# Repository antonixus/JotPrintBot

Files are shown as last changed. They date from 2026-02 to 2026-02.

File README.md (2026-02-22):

# JotPrintBot




<p align="center">
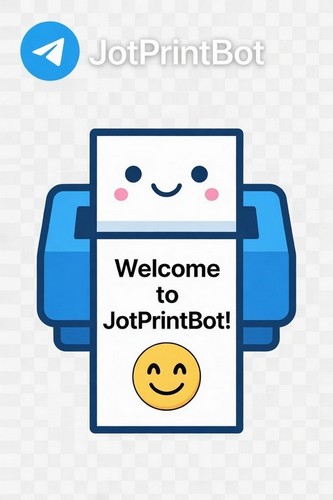
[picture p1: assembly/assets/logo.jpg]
JotPrintBot Logo
  
</p>

## Introduction

**JotPrintBot** is an asynchronous Python application that allows you to print text from Telegram messages to a thermal receipt printer. Send a message to the bot, and it will be printed on paper via a connected ESC/POS thermal printer.

**Supported hardware:**

- **CSN-A2 TTL** thermal printer (and other ESC/POS compatible models)
- **Raspberry Pi** / **DietPi** (serial connection via `/dev/serial0` or similar)
- Any Linux system with a serial or USB-Serial thermal printer

The bot uses [aiogram](https://docs.aiogram.dev/) for Telegram integration and [python-escpos](https://python-escpos.readthedocs.io/) for printer control.

---

## Functionality

- **Print text** — Send any text message (up to 1000 characters); it will be wrapped to the printer’s font width and queued for printing:
  - `FONT=a` (Font A): 32 characters per line
  - `FONT=b` (Font B): 42 characters per line
- **Print images** — Send a photo; it is resized to printer width (384 pixels), optionally rotated if landscape, and queued for printing. **Image enhancement** (contrast, sharpness, brightness, grayscale, dithering) improves thermal printer output quality
- **Whitelist access** — Only users in the whitelist can use the bot; others receive "Access denied"
- **Rate limiting** — 1 print per 10 seconds per user by default (configurable via `PRINT_RATE_LIMIT_SECONDS`)
- **Telegram formatting → printer styles** (when `PRINT_TELEGRAM_FORMATTING=true`):
  - `*bold*` → bold / emphasized text
  - `__underline__` → underlined text
  - `~strikethrough~` → inverted text (white‑on‑black style via `invert=True`)
  - `` `code` `` / triple‑backtick blocks → printed with Font **B** (`font='b'`, more compact/monospaced)
  - `> blockquote` → double‑size text (`double_height=True`, `double_width=True`)
  - `_italic_` entities are currently **ignored**
- **Commands:**
  - `/start` — Welcome message and usage instructions
  - `/status` — Check if the printer is online and paper status (adequate / near-end / no paper)
  - `/help` — List commands and limits
  - `/qr <text>` — Print the given text as a QR code (UTF-8 safe, supports Cyrillic)
- **Mock mode** — Run without a physical printer for development (`MOCK_PRINTER=true`)
- **Error handling** — Exceptions are logged and the admin is notified via Telegram

---

## Installation and Configuration

### Requirements

- Python 3.8+ (3.12 recommended)
- Serial thermal printer (or mock mode for testing)

On Raspberry Pi / Debian you also need some system libraries for Pillow and Tk:

```bash
sudo apt update
sudo apt install -y \
  libtiff6 libjpeg-dev zlib1g-dev libfreetype6-dev \
  liblcms2-dev libwebp-dev tcl8.6-dev tk8.6-dev python3-tk
```

### 1. Clone the repository

```bash
git clone https://github.com/antonixus/JotPrintBot.git
cd JotPrintBot
```

### 2. Create virtual environment and install dependencies

```bash
python -m venv venv
# Linux/macOS:
source venv/bin/activate
# Windows:
venv\Scripts\activate

pip install -r requirements.txt
```

### 3. Run setup (creates config, folders, and systemd service)

```bash
python setup.py
```

Setup creates the `logs/` folder, `.env` (if missing), and generates `bot.service` for systemd. On Raspberry Pi, install the service with:

```bash
python setup.py --install-service
```

### 4. Configure `.env`

Edit `.env` in the project root:

| Variable | Required | Description |
| --- | --- | --- |
| `BOT_TOKEN` | Yes | Telegram bot token from[@BotFather](https://t.me/BotFather) |
| `ADMIN_ID` | Yes | Your Telegram user ID (for error notifications) |
| `WHITELIST` | Yes | Comma-separated Telegram user IDs allowed to use the bot |
| `SERIAL_PORT` | No | Serial device (default:`/dev/serial0`) |
| `BAUDRATE` | No | Baud rate (default:`9600`) |
| `MOCK_PRINTER` | No | `true` to run without hardware (default: `false`) |
| `FONT` | No | Printer font code for python-escpos (default:`a`) |
| `DENSITY_LEVEL` | No | Print density 0–8 (default:`4`) |
| `PRINT_RATE_LIMIT_SECONDS` | No | Seconds between prints per user (default:`10`) |
| `PRINT_HEADER_ENABLED` | No | Print a header before every print (default:`true`) |
| `HEADER_LINE_WIDTH` | No | Header rule width in characters (default:`42`) |
| `CODEPAGE` | No | Python codec name for text encoding before sending to printer (default:`cp1251`) |
| `CODEPAGE_ID` | No | ESC/POS code page ID used with`ESC t` (on many printers `6` is cp1251; default: `6`) |
| `PRINTER_PROFILE` | No | python-escpos printer profile name (default:`RP326`) |
| `MEDIA_WIDTH_PIXELS` | No | Printer media width in pixels |
| `MEDIA_WIDTH_MM` | No | Printer media width in mm |
| `TEXT_UNDERLINE` | No | Default underline mode (0/1) for printer text (default:`0`) |
| `TEXT_ALIGN` | No | Default alignment for printer text:`left`, `center`, or `right` (default: `left`) |
| `TEXT_WIDTH` | No | Default width multiplier for printer text (default:`1`) |
| `TEXT_HEIGHT` | No | Default height multiplier for printer text (default:`1`) |
| `TEXT_INVERT` | No | Default invert mode (0/1) for printer text (default:`0`) |
| `TEXT_SMOOTH` | No | Default smoothing for printer text (default:`false`) |
| `TEXT_FLIP` | No | Default flip mode for printer text (default:`false`) |
| `SERIAL_BYTESIZE` | No | Serial byte size (default:`8`) |
| `SERIAL_PARITY` | No | Serial parity (default:`N`) |
| `SERIAL_STOPBITS` | No | Serial stop bits (default:`1`) |
| `SERIAL_TIMEOUT` | No | Serial timeout in seconds (default:`1.0`) |
| `SERIAL_DSRDTR` | No | Enable DSR/DTR flow control (default:`true`) |
| `QR_SIZE` | No | Default QR code pixel size 1–16 (default:`3`) |
| `QR_ALIGN` | No | Base alignment before printing QR codes:`left`, `center`, or `right` (default: `center`) |
| `QR_DENSITY` | No | Print density used for QR codes (default:`3`) |
| `QR_CENTER` | No | Center QR image when using software-rendered QR (default:`false`, example: `true`) |
| `QR_IMG_IMPL` | No | Image implementation for QR rendering:`bitImageRaster`, `graphics`, or `bitImageColumn` (default: `bitImageRaster`, example: `bitImageColumn`) |
| `IMAGE_IMPL` | No | ESC/POS image command for image printing:`bitImageRaster`, `graphics`, or `bitImageColumn` (default: `bitImageRaster`) |
| `IMAGE_FRAGMENT_HEIGHT` | No | Max height per fragment for large images (default:`960`) |
| `IMAGE_CENTER` | No | Center image horizontally (requires`MEDIA_WIDTH_PIXELS` to be set; default: `false`) |
| `IMAGE_DENSITY` | No | Print density for images (0–8, default:`5`) |
| `IMAGE_PRINT_WIDTH` | No | Target width in pixels for image resizing (default:`384` for CSN-A2) |
| `IMAGE_ENHANCE_ENABLED` | No | Enable/disable image enhancement (default:`true`) |
| `IMAGE_CONTRAST` | No | Contrast enhancement factor (default:`1.5`) |
| `IMAGE_SHARPNESS` | No | Sharpness enhancement factor (default:`2.0`) |
| `IMAGE_BRIGHTNESS` | No | Brightness adjustment factor (default:`1.0`) |
| `IMAGE_GRAYSCALE` | No | Convert to grayscale before printing (default:`true`) |
| `IMAGE_DITHERING` | No | Apply Floyd-Steinberg dithering for smooth gradients (default:`true`) |

**Raspberry Pi / DietPi:** Enable serial in `raspi-config` → Interface Options → Serial Port.

The printer connection uses UART serial. Many ESC/POS printers work with 9600 baud, 8N1, and (depending on model) may require DSR/DTR flow control. This project defaults to those values (see the “Printing Text” example in the CircuitDigest guide) and you can override them via `.env` if needed. See: [Thermal Printer Interfacing with Raspberry Pi](https://circuitdigest.com/microcontroller-projects/thermal-printer-interfacing-with-raspberry-pi-zero-to-print-text-images-and-bar-codes).

---

## Assembly

To build a portable JotPrintBot with a CSN-A2 printer and Raspberry Pi Zero W (including PD power and step-down to 5 V), follow the step-by-step guide:

**[Assembly instructions](assembly/ASSEMBLY_INSTRUCTIONS.md)** — BOM, wiring schematic, and wiring steps.

You can **3D print a printer case** to house the thermal printer, Raspberry Pi, and wiring. STEP and Bambu Lab Studio (3mf) model files are in [`assembly/3D_printing/`](assembly/3D_printing/); the same assembly instructions document includes recommended print settings (PLA, layer height, supports, etc.).
Or use prepared Bambulab printing profile: [Makerworld Bambulab Studio project](https://makerworld.com/ru/models/2431859-jotprintbot-portable-telegram-thermal-printer#profileId-2667653)

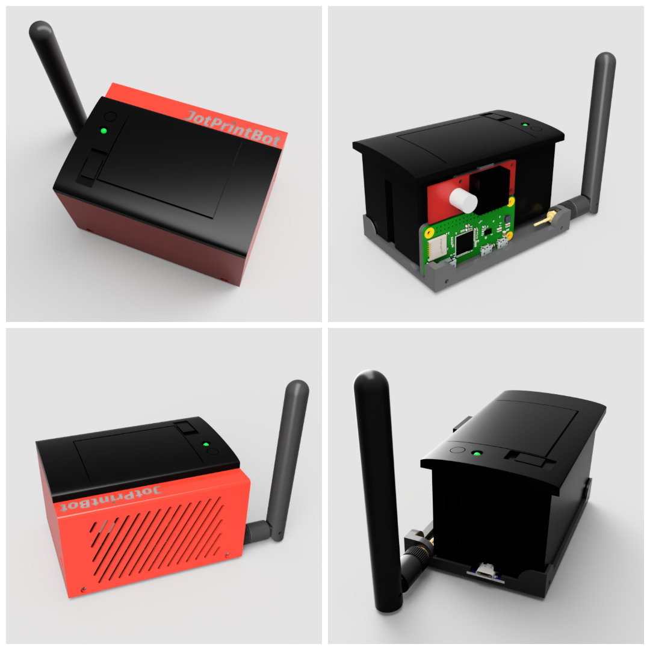
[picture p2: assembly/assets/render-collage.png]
JotPrintBot 3d model render


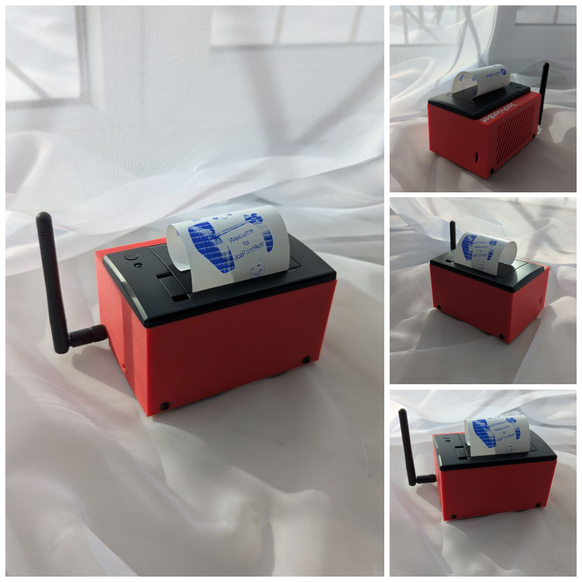
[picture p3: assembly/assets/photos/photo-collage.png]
JotPrintBot real device photo collage

---

## Usage

### Launch the application

```bash
python bot.py
```

The bot will start polling for updates. Send a message to your bot on Telegram to print it.

#### Run in background (screen)

```bash
screen -S bot python bot.py
```

Detach with `Ctrl+A`, then `D`. Reattach with `screen -r bot`.

#### Run as systemd service (Raspberry Pi)

Setup generates `bot.service` with the correct paths. Install for auto-start on boot:

```bash
python setup.py --install-service
sudo systemctl start bot
```

Or manually: copy `bot.service` to `/etc/systemd/system/`, edit paths if needed, then `sudo systemctl daemon-reload && sudo systemctl enable bot && sudo systemctl start bot`.

View status: `sudo systemctl status bot`. View logs: `journalctl -u bot -f`.

### Commands

| Command | Description |
| --- | --- |
| `/start`  | Welcome message and basic instructions |
| `/status` | Check if the printer is online and paper status |
| `/help` | List all commands and limits |
| `/qr` | Print a QR code with the given text |

### Limits

- **Rate:** 1 print per 10 seconds per user (default, configurable via `PRINT_RATE_LIMIT_SECONDS`)
- **Text length:** Maximum 1000 characters per message

### Image Printing

Send a photo to the bot to print it. The image will be:

- **Automatically resized** to the printer width (384 pixels for CSN-A2, configurable via `IMAGE_PRINT_WIDTH`)
- **Orientation handling:** Landscape images are rotated 90° clockwise before printing
- **Aspect ratio preserved:** Images are scaled proportionally to fit the printer width
- **Fragmentation:** Large images are automatically split into fragments (configurable via `IMAGE_FRAGMENT_HEIGHT`)
- **Image enhancement:** Improves print quality with contrast, sharpness, brightness, grayscale conversion, and dithering (configurable via `IMAGE_ENHANCE_ENABLED`, `IMAGE_CONTRAST`, `IMAGE_SHARPNESS`, `IMAGE_BRIGHTNESS`, `IMAGE_GRAYSCALE`, `IMAGE_DITHERING`)

**Supported formats:** JPEG, PNG (as sent by Telegram)

**Configuration options** (in `.env`):

- `IMAGE_IMPL`: Image printing command (`bitImageRaster`, `graphics`, or `bitImageColumn`)
- `IMAGE_FRAGMENT_HEIGHT`: Maximum height per fragment (default: `960`)
- `IMAGE_CENTER`: Center image horizontally (requires `MEDIA_WIDTH_PIXELS`; default: `false`)
- `IMAGE_DENSITY`: Print density 0–8 (default: `5`)
- `IMAGE_PRINT_WIDTH`: Target width in pixels (default: `384` for CSN-A2)
- `IMAGE_ENHANCE_ENABLED`: Enable/disable image enhancement (default: `true`)
- `IMAGE_CONTRAST`: Contrast enhancement factor (default: `1.5`)
- `IMAGE_SHARPNESS`: Sharpness enhancement factor (default: `2.0`)
- `IMAGE_BRIGHTNESS`: Brightness adjustment factor (default: `1.0`)
- `IMAGE_GRAYSCALE`: Convert to grayscale before printing (default: `true`)
- `IMAGE_DITHERING`: Apply Floyd-Steinberg dithering for smooth gradients (default: `true`)

**Note:** Pillow is required for image processing and is listed in `requirements.txt`. On Raspberry Pi, ensure system libraries for Pillow are installed (see Installation section).

### Image Enhancement

The bot applies image preprocessing techniques to improve thermal printer output quality:

- **Grayscale conversion** — Thermal printers work best with B&W images
- **Contrast enhancement** — Improves black/white distinction
- **Sharpness enhancement** — Makes edges more defined
- **Brightness adjustment** — Optimizes for thermal paper
- **Floyd-Steinberg dithering** — Smooth gradients for thermal printing

**Configuration** (in `.env`):

```bash
IMAGE_ENHANCE_ENABLED=true
IMAGE_CONTRAST=1.5
IMAGE_SHARPNESS=2.0
IMAGE_BRIGHTNESS=1.0
IMAGE_GRAYSCALE=true
IMAGE_DITHERING=true
```

For fine-tuning parameters for your specific printer, see [`DEPLOYMENT_GUIDE.md`](DEPLOYMENT_GUIDE.md:1).

---

## Tests

The project uses [pytest](https://docs.pytest.org/) with [pytest-asyncio](https://pytest-asyncio.readthedocs.io/) for async tests.

### Run all tests

```bash
pytest test/ -v
```

### Image enhancement tests

```bash
pytest test/image_enhancement.py -v   # Unit tests for image enhancement
pytest test/test_printer.py -v        # Integration tests for image printing
```

### Run specific test files

```bash
pytest test/test_printer.py -v   # Printer module with mock (text & QR)
pytest test/test_wrapping.py -v  # Font-based wrapping expectations
pytest test/test_encoding.py -v  # Cyrillic encoding on real printer (requires hardware)
```

### Test coverage

Tests cover:

- **Printer (mock):** Initialization, `print_text`, `print_qr`, `print_task`, `status`, and image printing (`_do_print_image`) in mock mode
- **Image enhancement:** Unit tests in `test/image_enhancement.py` for `_enhance_image()` (contrast, sharpness, brightness, grayscale, dithering, and disabled path)
- **Wrapping helper scripts:** How many characters fit per line for different fonts
- **Encoding helper script:** Cyrillic output validation using the configured printer profile and code page

For QR-specific manual testing, you can also use:

```bash
python -m test.qr_print_test "Hello" --impl bitImageColumn --center
```

---

## Logging

Logging is configured with a **rotating file handler**:

- **File:** `logs/app.log`
- **Max size:** 10 MB per file
- **Backup count:** 5 (keeps up to 5 rotated files)
- **Level:** INFO

**Logged events include:**

- `Message received` — When text is queued for printing
- `Printed` / `Printed (mock)` — When a print job completes
- Errors with full tracebacks (print failures, handler exceptions, status check failures)

Logs are written to `logs/` (created automatically on startup). Ensure the application has write permissions to the project directory.

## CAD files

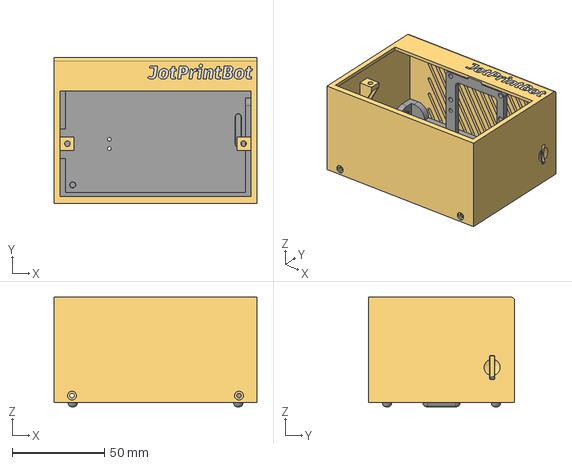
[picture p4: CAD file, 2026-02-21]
assembly/3D_printing/Printer Case.step
110.0 x 79.3 x 59.5 mm
Case bottom
Text

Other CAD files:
assembly/3D_printing/Printer Case.3mf

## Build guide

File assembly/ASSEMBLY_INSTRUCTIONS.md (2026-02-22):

# Assembly Instructions

This guide describes how to build a portable JotPrintBot setup using a CSN-A2 thermal printer, Raspberry Pi Zero W, and a USB Type-C PD power path. Follow the steps in order and observe polarity and voltage ratings.

> **Safety:** Double-check polarity before applying power. The Raspberry Pi GPIO has no reverse-polarity protection. Use a Quick Charge / PD power supply that supports 12 V output via the trigger module.

---

## BOM (Bill of Materials)

### Electronics

| # | Component | Photo | Info / Links |
| --- | --- | --- | --- |
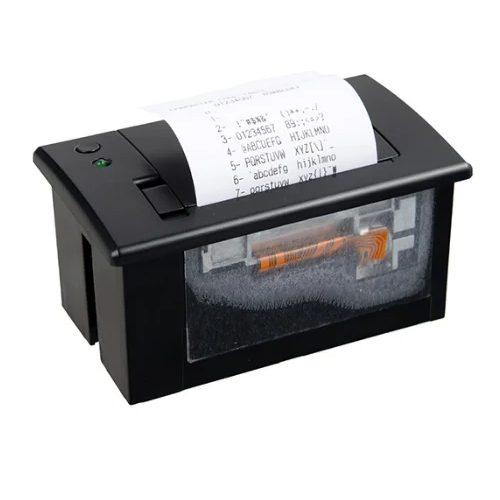
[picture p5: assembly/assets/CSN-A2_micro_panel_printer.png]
CSN-A2
| 1 | CSN-A2 Micro panel printer |  | ESC/POS, 9V/12V /[Manual](https://cdn-shop.adafruit.com/datasheets/CSN-A2+User+Manual.pdf) / [Shop Ali](https://ali.click/gpp8018) |
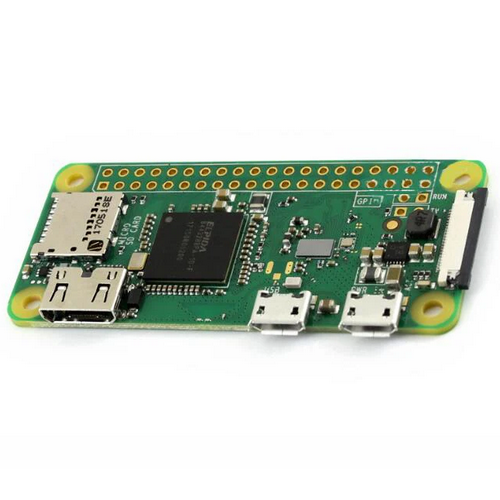
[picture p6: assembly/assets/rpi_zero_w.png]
RPi Zero W
| 2 | Raspberry Pi Zero W |  | [PDF](https://cdn.sparkfun.com/assets/learn_tutorials/6/7/6/PiZero_1.pdf) / [Shop Ali](https://ali.click/dmq801y) |
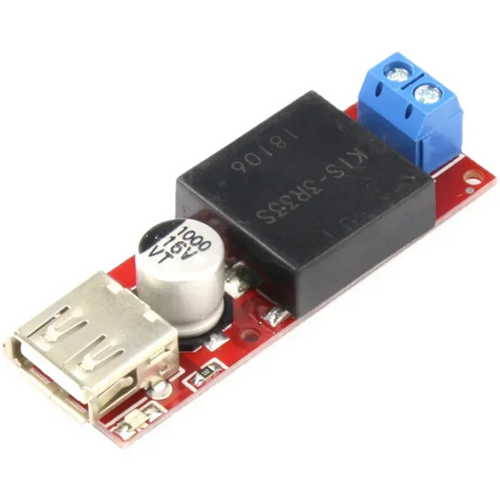
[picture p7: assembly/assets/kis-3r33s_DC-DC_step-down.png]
KIS-3R33S
| 3 | KIS-3R33S DC-DC step-down module |  | [Datasheet](https://www.datasheetcafe.com/wp-content/uploads/2016/05/KIS-3R33S.pdf) / [Shop Ali](https://ali.click/ker801a) |
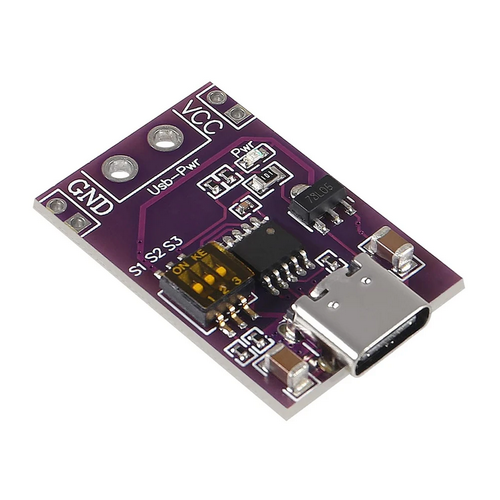
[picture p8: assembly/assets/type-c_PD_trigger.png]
Type-C PD trigger
| 4 | USB Type-C QC/PD/AFC Trigger board |  | 5/9/12/15/20V / [Manual](https://manuals.plus/asin/B0CDWXN1WR) / [Shop Ali](https://ali.click/p1t8018) |
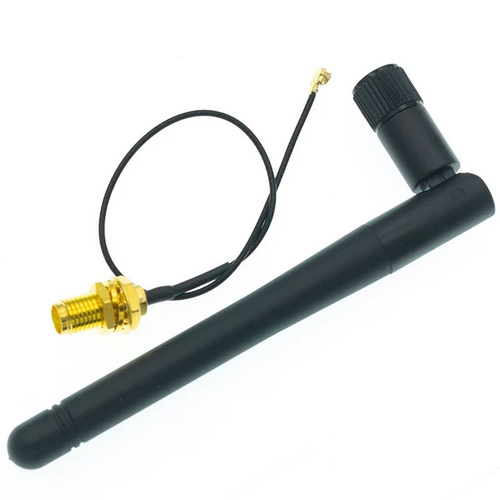
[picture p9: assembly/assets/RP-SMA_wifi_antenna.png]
RP-SMA antenna
| 5 | 2.4 GHz Wi-Fi antenna 2 dBi RP-SMA |   | [Shop Ali](https://ali.click/ort801m) |

### Fasteners

- M3 × 4 mm bolts (round head or flat head) — 13 pcs
- M2.5 × 5 mm bolts — 2 pcs
- M3 threaded inserts (e.g. 4 mm length) — 8 pcs

### Wires

- **24 AWG:** red, black — ~15 cm each
- **28 AWG:** red, black, green, yellow — ~10 cm each

### Power supply

Quick Charge / PD power supply that supports 12 V output when used with the PD trigger module.

### Tools

- Mini side nippers
- Cyanoacrylate glue
- Allen keys (for bolt sizes above)

---

## Electronic parts wiring

### Schematic

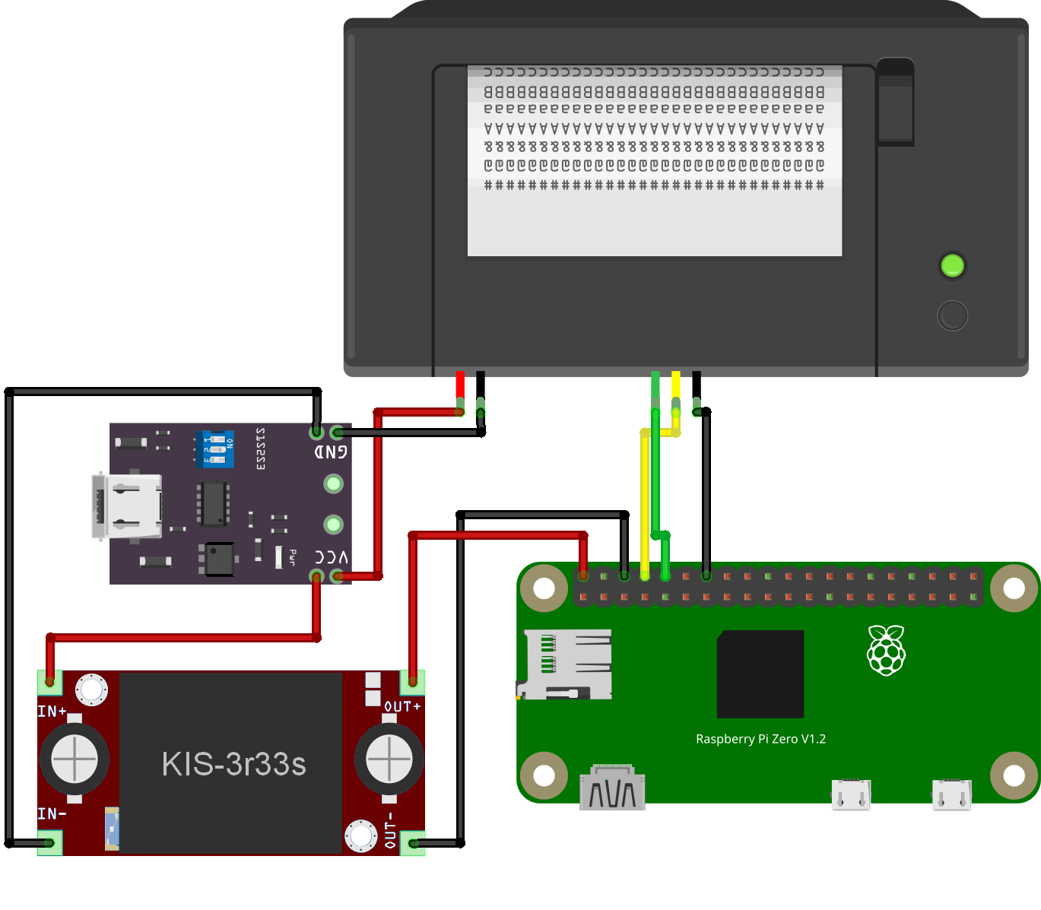
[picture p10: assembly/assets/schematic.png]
Wiring schematic


### Wiring steps

1. **Set PD trigger to 12 V**
   Switch the USB Type-C QC/PD/AFC Trigger-Decoy board to 12 V mode as indicated on the back of the board.
2. **Printer power**Connect the PD trigger outputs to the printer power connector:

   - PD **VCC out** → printer **VH** (or +12 V)
   - PD **GND out** → printer **GND**
3. **Step-down input**Using a second pair of wires from the same PD trigger outputs, feed the KIS-3R33S step-down module:

   - PD **GND out** → step-down **IN-**
   - PD **VCC out** → step-down **IN+**
4. **Raspberry Pi power**Connect the step-down outputs to the Raspberry Pi Zero W GPIO power pins:

   - Step-down **OUT+** → RPi **PIN 2** (+5 V)
   - Step-down **OUT-** → RPi **PIN 6** (GND)

   > **Caution:** Reversed polarity on the GPIO power pins can damage the Raspberry Pi. There is no reverse-polarity protection.
   >
5. **Printer serial (UART)**Connect the CSN-A2 TTL connector to the Raspberry Pi UART (cross TX/RX):

   - Printer **RXD** (receive) → RPi **PIN 8** (TXD/GPIO14)
   - Printer **TXD** (send) → RPi **PIN 10** (RXD/GPIO15)
   - Printer **TTL GND** → RPi **PIN 14** (GND)

After wiring, enable the serial port on the Pi: `raspi-config` → Interface Options → Serial Port (login shell can be disabled; serial port enabled).

---

## Case: 3D printing

[Makerworld Bambulab Studio project](https://makerworld.com/ru/models/2431859-jotprintbot-portable-telegram-thermal-printer#profileId-2667653)

A 3D-printed case allows you to house the printer, Raspberry Pi, and wiring in one unit. Model files are in the `assembly/3D_printing/` folder.

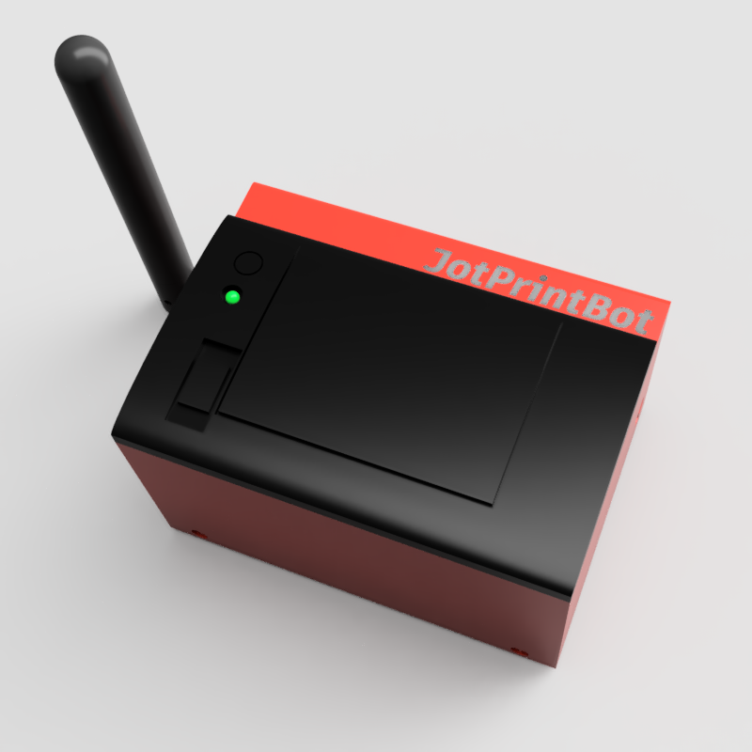
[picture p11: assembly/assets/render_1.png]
Case render


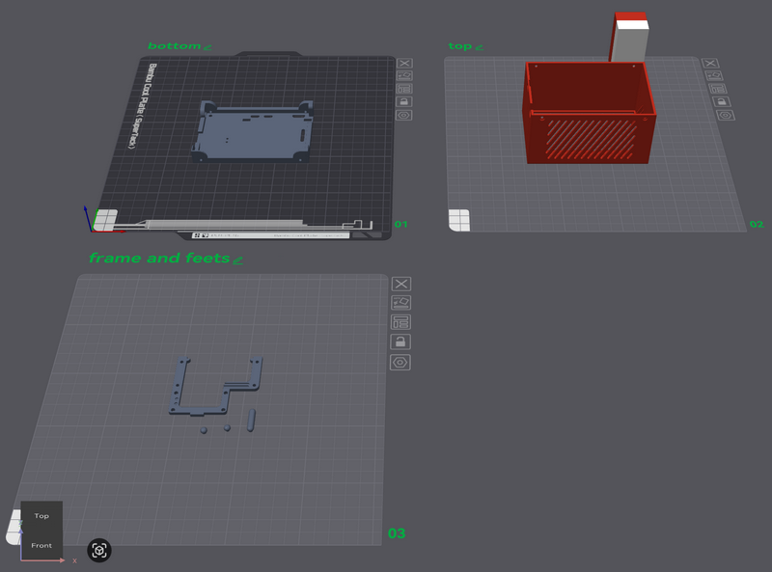
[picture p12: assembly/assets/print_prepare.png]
Print preparation


### 3D model files

| File | Description |
| --- | --- |
| `Printer Case.step` | Model for printing and customization (STEP format) |
| `Printer Case.3mf`  | Bambu Lab Studio project with profile for Bambu Lab X1C |

Location: **`assembly/3D_printing/`**

### Printing parameters

- **Material:** PLA
- **Layer height:** 0.08 mm
- **Walls:** 3
- **Top layers:** 9
- **Bottom layers:** 7
- **Infill:** 15%
- **Supports:** Yes (normal + snug)

> Use a brim for small parts (e.g. legs). Use cyanoacrylate glue to attach legs to the case.

---

## Assembled device

Assembled device

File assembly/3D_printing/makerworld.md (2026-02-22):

# JotPrintBot: Portable Telegram Thermal Printer Case for Raspberry Pi Zero W and CSN-A2

## Project Overview

JotPrintBot is a compact, portable device that turns a standard thermal receipt printer into a smart Telegram-connected printer. Send text messages, QR codes, or images via Telegram, and the bot will queue and print them on the CSN-A2 TTL thermal printer. This project includes a custom 3D-printable case to house the Raspberry Pi Zero W, printer, and electronics for a clean, integrated build.

**Key Features:**
- **Telegram Integration:** Print messages, photos, and QR codes directly from Telegram chats.
- **Portable Design:** Powered via USB-C with PD/QC trigger for 12V output, stepped down to 5V for the Pi.
- **Customizable Case:** 3D-printable enclosure with space for wiring and easy assembly.
- **Software:** Open-source Python bot with support for text formatting, image enhancement (contrast, sharpness, dithering), and more.
- **Hardware Compatibility:** Designed for CSN-A2 printer and Raspberry Pi Zero W, but adaptable to similar ESC/POS printers.

This build is perfect for makers who want a fun IoT project: create a "message printer" for notes, receipts, or even automated alerts. The case ensures everything is secure and portable.

JotPrintBot Render Collage

JotPrintBot Photo Collage

## Bill of Materials (BOM)

### Electronics
| # | Component | Quantity | Notes / Links |
|---|---|---|---|
| 1 | CSN-A2 Micro panel printer | 1 | ESC/POS, 9V/12V. [AliExpress](https://ali.click/gpp8018) |
| 2 | Raspberry Pi Zero W | 1 | [AliExpress](https://ali.click/dmq801y) |
| 3 | KIS-3R33S DC-DC step-down module | 1 | [Datasheet](https://www.datasheetcafe.com/wp-content/uploads/2016/05/KIS-3R33S.pdf), [AliExpress](https://ali.click/ker801a) |
| 4 | USB Type-C QC/PD/AFC Trigger board | 1 | 5/9/12/15/20V. [Manual](https://manuals.plus/asin/B0CDWXN1WR), [AliExpress](https://ali.click/p1t8018) |
| 5 | 2.4 GHz Wi-Fi antenna 2 dBi RP-SMA | 1 | [AliExpress](https://ali.click/ort801m) |

### Fasteners
- M3 × 4 mm bolts (round or flat head) — 13 pcs
- M2.5 × 5 mm bolts — 2 pcs
- M3 threaded inserts (e.g., 4 mm length) — 4 pcs

### Wires
- 24 AWG: red, black — ~15 cm each
- 28 AWG: red, black, green, yellow — ~10 cm each

### Power Supply
- Quick Charge / PD power supply supporting 12V output.

### Tools
- Mini side nippers
- Cyanoacrylate glue
- Allen keys (for bolt sizes)

## 3D Printing Files

All files are located in the `assembly/3D_printing/` folder of the GitHub repository.

| File Name | Description | Format |
|---|---|---|
| Printer Case.step | Full model for customization and printing | STEP |
| Printer Case.3mf | Bambu Lab Studio project with print profile | 3MF |

Download the files from [GitHub: assembly/3D_printing](https://github.com/antonixus/JotPrintBot/tree/main/assembly/3D_printing).

## Print Settings

- **Material:** PLA
- **Layer Height:** 0.08 mm
- **Walls:** 3
- **Top Layers:** 9
- **Bottom Layers:** 7
- **Infill:** 15%
- **Supports:** Yes (normal + snug)
- **Brim:** Recommended for small parts like legs

Use cyanoacrylate glue to attach the legs to the case after printing.

Print Preparation

## Assembly Instructions

### Step 1: Wiring the Electronics
Follow the schematic below for connections. Double-check polarity to avoid damage.

Wiring Schematic

1. Set the PD trigger board to 12V mode (as marked on the board).
2. Connect PD trigger outputs to printer power: VCC out → VH (+12V), GND out → GND.
3. Connect PD trigger outputs to step-down module: VCC out → IN+, GND out → IN-.
4. Connect step-down outputs to Raspberry Pi: OUT+ → PIN 2 (+5V), OUT- → PIN 6 (GND).
5. Connect printer serial: RXD → PIN 8 (TXD/GPIO14), TXD → PIN 10 (RXD/GPIO15), TTL GND → PIN 14 (GND).

Enable serial on Raspberry Pi: Run `raspi-config` → Interface Options → Serial Port (disable login shell, enable serial port).

### Step 2: Assemble the Case
1. Insert M3 threaded inserts into the case holes (use a soldering iron or insert tool).
2. Mount the Raspberry Pi Zero W using M2.5 × 5 mm bolts.
3. Secure the CSN-A2 printer with M3 × 4 mm bolts.
4. Route wires through the case channels and secure components.
5. Attach the legs with glue.
6. Close the case with remaining M3 bolts.

### Step 3: Software Setup
1. Clone the repository: `git clone https://github.com/antonixus/JotPrintBot.git`.
2. Create venv and install dependencies: `python -m venv venv`, activate, `pip install -r requirements.txt`.
3. Run `python setup.py` to create .env and logs.
4. Edit .env with your BOT_TOKEN, ADMIN_ID, WHITELIST, and other settings.
5. Launch: `python bot.py` or install as systemd service.

For full software details, see the [GitHub README](https://github.com/antonixus/JotPrintBot?tab=readme-ov-file#readme-ov-file).

## Additional Resources

- **GitHub Repository:** [https://github.com/antonixus/JotPrintBot](https://github.com/antonixus/JotPrintBot)
- **Printer Manual:** [CSN-A2 User Manual](https://cdn-shop.adafruit.com/datasheets/CSN-A2+User+Manual.pdf)

If you print this case, share your makes and feedback! Happy printing! 🚀

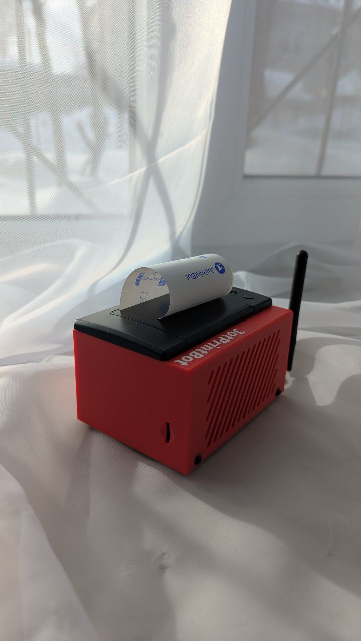
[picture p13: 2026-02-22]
assembly/assets/photos/photo_2.jpg

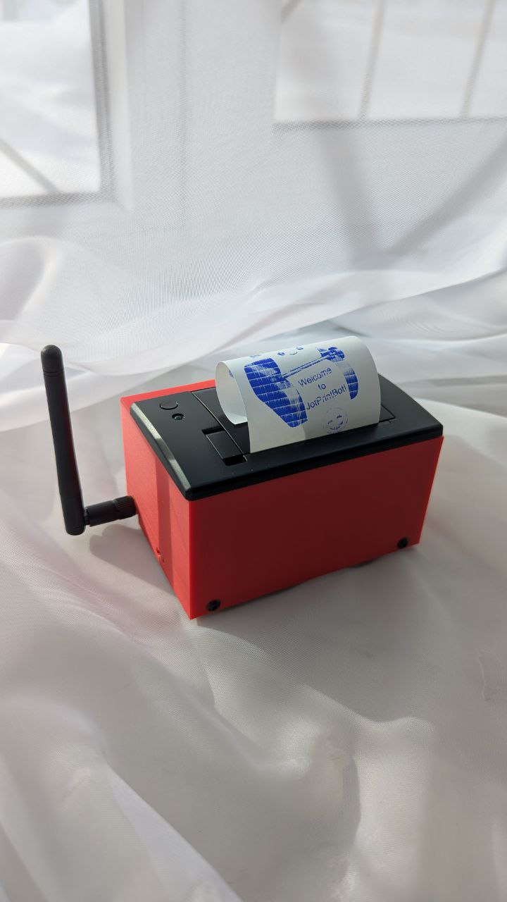
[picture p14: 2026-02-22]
assembly/assets/photos/photo_1.jpg

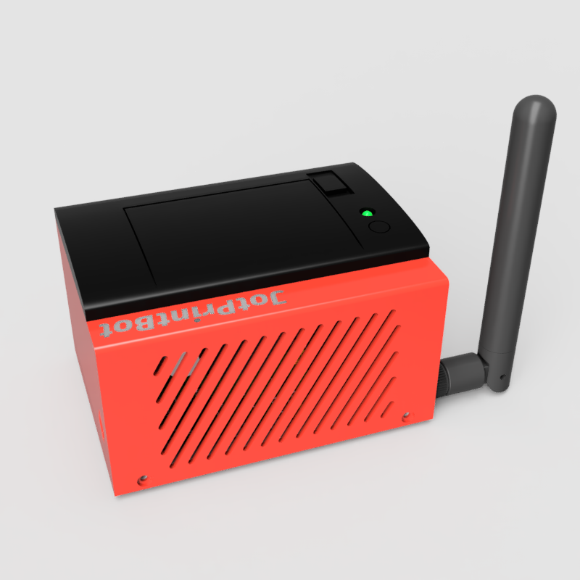
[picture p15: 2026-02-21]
assembly/assets/render_2.png

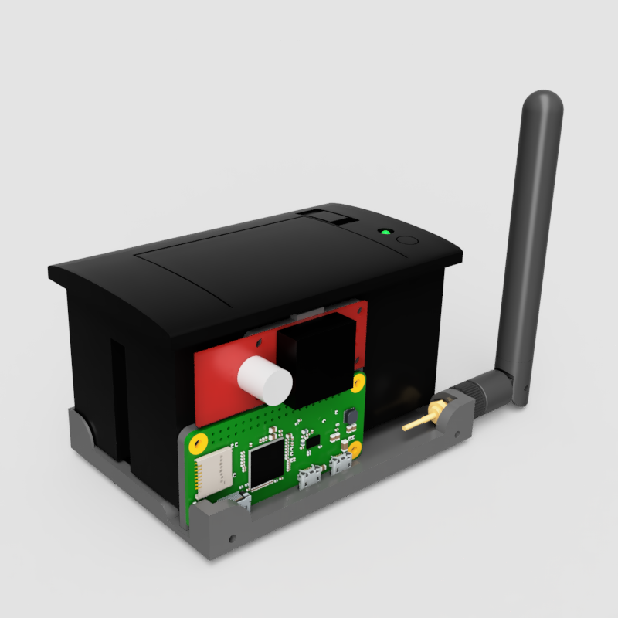
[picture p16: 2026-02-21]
assembly/assets/render_3.png

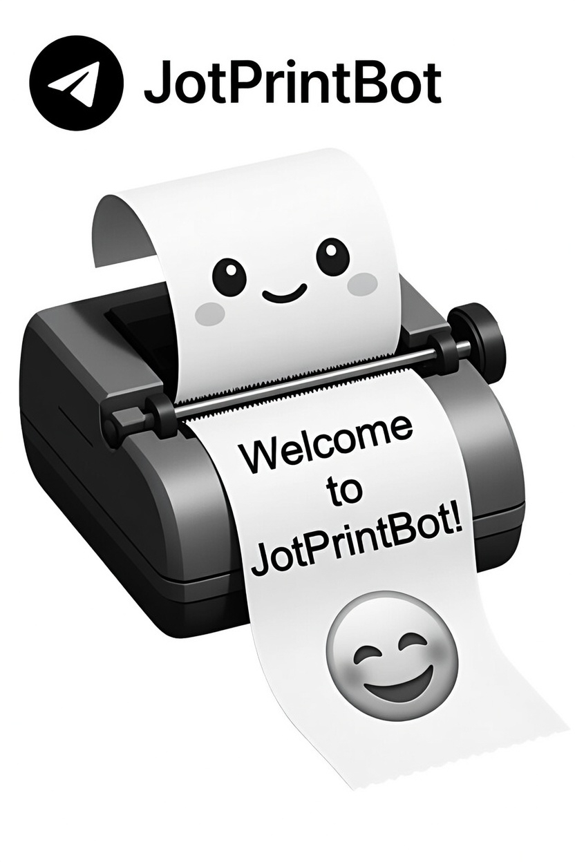
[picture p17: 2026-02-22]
assembly/assets/welcome_bw.jpg

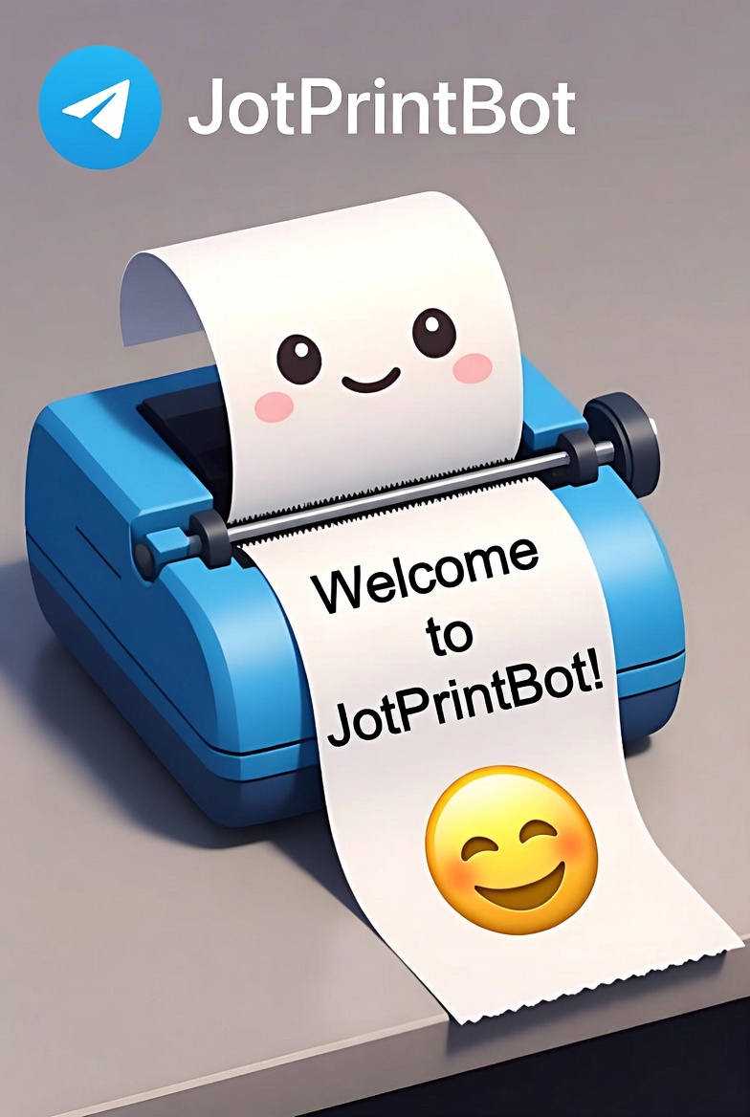
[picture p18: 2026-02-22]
assembly/assets/welcome.jpg

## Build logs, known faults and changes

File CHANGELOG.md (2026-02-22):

## JotPrintBot v0.1.5 – Image enhancement and assembly documentation

### Image enhancement for thermal printing

- **Image preprocessing pipeline**:
  - Added `_enhance_image()` in `printer.py` to improve thermal printer output quality.
  - Pipeline: grayscale conversion (optional), contrast, sharpness, brightness (PIL `ImageEnhance`), then Floyd-Steinberg dithering (`Image.convert("1", dither=Image.FLOYDSTEINBERG)`).
  - Enhancement runs after resize and before sending to the printer so dithering uses final-resolution pixels.
- **Configuration via `.env`**:
  - `IMAGE_ENHANCE_ENABLED` – enable/disable enhancement (default: `true`).
  - `IMAGE_CONTRAST` – contrast factor (default: `1.5`).
  - `IMAGE_SHARPNESS` – sharpness factor (default: `2.0`).
  - `IMAGE_BRIGHTNESS` – brightness factor (default: `1.0`).
  - `IMAGE_GRAYSCALE` – convert to grayscale before printing (default: `true`).
  - `IMAGE_DITHERING` – apply Floyd-Steinberg dithering (default: `true`).
- **Documentation**: README Image Enhancement subsection, configuration table, and `DEPLOYMENT_GUIDE.md` reference for fine-tuning.

### Assembly and hardware documentation

- **README**: New **Assembly** section with link to step-by-step assembly instructions, note on 3D-printing a printer case (models in `assembly/3D_printing/`), and placeholder for a photo of the assembled device.
- **Assembly instructions** (`assembly/ASSEMBLY_INSTRUCTIONS.md`): Improved structure, safety note, BOM fixes (typos, duplicate line), clearer wiring steps and image paths, 3D print parameters table, and “Assembled device” photo placeholder.

### Tests

- **Image enhancement**: New `test/image_enhancement.py` with unit tests for `_enhance_image()` (contrast, sharpness, brightness, grayscale, dithering, and disabled-enhancement path).
- **Printer image tests**: `test/test_printer.py` – `TestAsyncPrinterPrintImage` tests for image printing with enhancement in mock mode (using temporary image files).

---

## JotPrintBot v0.1.4 – Image printing and printer state management

### Image printing feature

- **Photo printing support**:
  - Added `ImagePayload` to `print_tasks.py` to support image printing in the unified print queue.
  - New photo handler in `bot.py` using `F.photo` filter to handle Telegram photo messages.
  - Photos are downloaded to temporary files, queued as `PrintTask` with `ImagePayload`, and automatically cleaned up after printing.
- **Image processing**:
  - Implemented `_do_print_image()` in `printer.py` using PIL (Pillow) for image manipulation.
  - Automatic orientation handling: landscape images are rotated 90° clockwise before printing.
  - Automatic resizing to printer width (384 pixels for CSN-A2, configurable via `IMAGE_PRINT_WIDTH`) while preserving aspect ratio.
  - Large images are automatically fragmented (configurable via `IMAGE_FRAGMENT_HEIGHT`).
- **Image printing configuration via `.env`**:
  - `IMAGE_IMPL` – ESC/POS image command: `bitImageRaster`, `graphics`, or `bitImageColumn` (default: `bitImageRaster`).
  - `IMAGE_FRAGMENT_HEIGHT` – Maximum height per fragment for large images (default: `960`).
  - `IMAGE_CENTER` – Center image horizontally (requires `MEDIA_WIDTH_PIXELS`; default: `false`).
  - `IMAGE_DENSITY` – Print density 0–8 for images (default: `5`).
  - `IMAGE_PRINT_WIDTH` – Target width in pixels for image resizing (default: `384` for CSN-A2).
- **Dependencies**:
  - Added `Pillow>=9.0.0` to `requirements.txt` for image processing.

### Printer state management fixes

- **Printer re-initialization after graphics mode**:
  - Added `_reinitialize_printer()` method to reset printer state after image/QR printing.
  - Fixes issue where text printed after images would appear garbled or blurry until printer power cycle.
  - Sends ESC @ (Initialize) and ESC t (code page) commands to fully reset printer to text mode.
  - Applied after both image printing and QR code printing (which uses image mode when `native=False`).

### Configuration and documentation improvements

- **`.env` file organization**:
  - Reorganized `.env.example` and `setup.py` template into functional blocks with comment headers:
    - Core bot / security
    - Printer connection (Serial / UART)
    - Printer profile / media / encoding
    - Default text rendering
    - Telegram entities → printer styles
    - Per-message header printing
    - QR printing
    - Image printing
  - Improved readability and maintainability of configuration files.

## JotPrintBot v0.1.3 – Per-message headers, text formatting and unified print queue

### Per-message header feature

- **Optional header before each print**:
  - Added `PRINT_HEADER_ENABLED` (default: `true`) to control whether a header is printed before each message.
  - Header includes: timestamp (`[DD.MM.YY HH:MM:SS]`), Telegram username (`@username` or `@id123456`), horizontal rule line, and blank line.
  - Header is printed using Font B (`font='b'`) for better readability.
- **Header configuration via `.env`**:
  - `PRINT_HEADER_ENABLED` – enable/disable header printing (default: `true`).
  - `HEADER_LINE_WIDTH` – width of the horizontal rule line in characters (default: `42`, should match your printer font width).
- **Unified print queue model**:
  - Introduced `print_tasks.py` with dataclasses: `HeaderInfo`, `TextPayload`, `QrPayload`, `PrintTask`.
  - All print operations (text, formatted text, QR codes) now use the same `PrintTask(header, payload)` structure.
  - Header is optional (`header: HeaderInfo | None`), allowing the same queue model for all print types.

### Bot improvements

- **Enhanced error handling**:
  - Bot now uses aiogram formatting helpers (`Text`, `Bold`) with `ParseMode.MARKDOWN_V2` for consistent message formatting.
  - Error messages sent to admin are properly escaped for MARKDOWN_V2 syntax.
  - Improved error handling in `/start` and `/help` handlers.
- **Message handling**:
  - Text and QR handlers now build `PrintTask` objects with optional headers based on `PRINT_HEADER_ENABLED`.
  - Queue integration remains the same (`printer.queue.put(task)`), but now uses the unified `PrintTask` model.

### Text formatting

- **Telegram formatting → printer styles** (when `PRINT_TELEGRAM_FORMATTING=true`):
  - `*bold*` → bold / emphasized text
  - `__underline__` → underlined text
  - `~strikethrough~` → inverted text (white‑on‑black style via `invert=True`)
  - `` `code` `` / triple‑backtick blocks → printed with Font **B** (`font='b'`, more compact/monospaced)
  - `> blockquote` → double‑size text (`double_height=True`, `double_width=True`)
  - `_italic_` entities are currently **ignored**
- **Telegram entity parsing**:
  - Improved UTF-16 code unit to Python string index conversion for accurate entity range extraction.
  - Better handling of edge cases (empty text, malformed entities, missing entity lists).
  - Formatter now correctly handles both `message.entities` and `message.caption_entities`.

### Printer module updates

- **Unified print task processing**:
  - `AsyncPrinter._do_print_task()` now handles `PrintTask` objects with optional headers.
  - Header is printed first (if present) using `_print_header()`, then payload (text or QR) is printed.
  - Style reset after header ensures payload printing starts with clean defaults.
- **Mock mode support**:
  - Mock printer logs `Printed task (mock): ...` with preview of payload content (text or QR).
  - Header printing is skipped in mock mode (header info is still logged in task preview).

### Testing

- **Extended test coverage**:
  - Added tests for `PrintTask` model and header functionality in `test_bot.py` and `test_printer.py`.
  - Tests verify that headers are included/excluded based on `PRINT_HEADER_ENABLED` config.
  - Formatter tests cover UTF-16 range conversion and entity mapping edge cases.

### Internal refactors

- **Code organization**:
  - Moved print task model to dedicated `print_tasks.py` module for better separation of concerns.
  - Header building logic centralized in `_build_header_info()` helper function.
  - Consistent use of dataclasses (`@dataclass(frozen=True)`) for immutable task models.

## JotPrintBot v0.1.2 – Bugfixes

### Bugfixes

- **Text wrapping behavior**:
  - Simplified message handling so the bot now forwards the raw, stripped text to `AsyncPrinter`, leaving any wrapping and layout decisions to the printer side.
  - This avoids double-wrapping and makes manual test scripts (`test_wrapping.py`, `test_encoding.py`) the single source of truth for line width experiments.
- **Configuration correctness**:
  - Fixed `MEDIA_WIDTH_MM` in `config.py` to be wired to its own environment variable instead of reusing `MEDIA_WIDTH_PIXELS`.
  - Adjusted default QR-related settings (`QR_SIZE`, `QR_IMG_IMPL`) to match the actual code defaults used by `AsyncPrinter`.
- **Documentation consistency**:
  - Updated README to reference JotPrintBot (new repo name) and corrected examples for manual QR testing to align with the current defaults.

## JotPrintBot v0.1.1 – QR codes, font-based wrapping, and config tweaks

### QR code printing

- **New `/qr` command**:
  - Added `/qr <text>` Telegram command to print a QR code for the given text.
  - Uses software-rendered QR (`native=False`) so QR contents are encoded as UTF‑8 and decode correctly on smartphones, including Cyrillic text (e.g. `Привет`).
- **QR configuration via `.env`**:
  - `QR_SIZE` – default QR module size (1–16).
  - `QR_ALIGN` – base alignment before printing QR codes (`left`, `center`, or `right`).
  - `QR_DENSITY` – printer density value applied when printing QR codes.
  - `QR_CENTER` – whether to center QR images when using software-rendered QR.
  - `QR_IMG_IMPL` – image implementation for QR rendering: `bitImageRaster`, `graphics`, or `bitImageColumn`.
- **Internal `AsyncPrinter` updates**:
  - Added `print_qr()` method with retry logic mirroring `print_text()`.
  - QR printing now uses `image_arguments` to control centering and image implementation, based on the new `.env` settings.
  - In mock mode, QR prints are logged as `QR printed (mock): ...` for easier testing.

### Text wrapping & font behavior

- **Font-based wrapping in the bot**:
  - Incoming text is now wrapped based on the configured printer font (`FONT`):
    - `FONT=a` (Font A): 42 characters per line.
    - `FONT=b` (Font B): 56 characters per line.
  - This matches typical capabilities for 57mm ESC/POS printers and better utilizes available width.
- Updated `test_wrapping` and helper scripts (manual tools) to reflect the expected character counts for different fonts.

### Status output and UX

- **Improved `/status` output**:
  - The `/status` command now reports paper status as human-readable text instead of raw digits:
    - `adequate`, `near-end`, or `no paper`.
- Rate limit documentation was aligned with the current default:
  - `PRINT_RATE_LIMIT_SECONDS` default is now documented as **10 seconds**.

### QR testing utilities & docs

- Added `test/qr_print_test.py`:
  - Standalone script for printing a QR code with configurable options:
    - `--qr-size`, `--impl` (`bitImageRaster`, `graphics`, or `bitImageColumn`),
    - `--center`, `--high-density-vertical`, `--high-density-horizontal`,
    - `--density`, and an optional `--native` flag for native QR mode experiments.
  - Default content is `Привет`, which is useful for visually verifying Cyrillic decoding on smartphones.

## JotPrintBot v0.1.0 – Printer configuration, Cyrillic support, and improved bot UX

### Printer configuration & encoding

- **New serial config options**: Added `.env` options for printer serial settings, including `SERIAL_BYTESIZE`, `SERIAL_PARITY`, `SERIAL_STOPBITS`, `SERIAL_TIMEOUT`, and `SERIAL_DSRDTR`.
- **Codepage and profile support**:
  - Introduced `CODEPAGE` (Python codec, default `cp1251`) to control how text is encoded before sending to the printer.
  - Added `CODEPAGE_ID` (ESC/POS code page ID, default `6` for cp1251) to select the correct hardware code page via `ESC t`.
  - Added `PRINTER_PROFILE` (default `RP326`) so `python-escpos` can use the correct printer capabilities.
- **`AsyncPrinter` updates**:
  - Initializes the printer and explicitly selects the configured ESC/POS code page using `ESC @` and `ESC t <CODEPAGE_ID>`.
  - Uses `python-escpos` `set()` for text style (font, density, width/height, underline, invert, smooth, flip) based on `.env` settings.
  - Encodes text using the configured `CODEPAGE` while preserving correct Cyrillic output on printers where code page 6 is `cp1251`.

### Status reporting

- **Enhanced `/status` command**:
  - Now shows **online status** using `escpos.is_online()`.
  - Also reports **paper status** using `escpos.paper_status()`:
    - `2` – paper adequate
    - `1` – paper near end
    - `0` – no paper
    - `unknown` – when the printer does not support status queries or an error occurs.
- **Mock support**:
  - Mock printer now implements `is_online()` and `paper_status()` so tests and mock mode are consistent with real hardware.

### Rate limiting improvements

- **Configurable print rate**:
  - Print rate limit is now controlled via `PRINT_RATE_LIMIT_SECONDS` (default **20 seconds** between prints per user).
- **Scoped rate limiting**:
  - `ThrottlingMiddleware` applies the limit **only to actual print messages**, not to commands.
  - Commands `/start`, `/help`, `/status`, and non-user events are no longer throttled.
- **Improved error message**:
  - When the rate limit is exceeded, users now see:
    - `Print rate limit exceeded. Limit 1 print per XX sec.`
    - `Please wait XX sec and try again.`

### Bot UX & commands

- `/help` output now shows the current print rate limit dynamically based on `PRINT_RATE_LIMIT_SECONDS`.
- `/start` and `/status` behaviors are preserved but are **never blocked** by the print rate limiter.

### Printer testing utilities

- `test/codepage_tables.py`:
  - Prints ESC/POS code page tables on the thermal printer.
  - Useful for verifying code page mappings and character sets for different printers.
- `test/test_encoding.py`:
  - Verifies Cyrillic output via `python-escpos.textln` using the configured printer profile and code page.
  - Confirms that text printed through the app matches raw cp1251 output behavior.

### Internal refactors & tests

- Centralized serial and text-style configuration in `config.py` and wired it through `AsyncPrinter`.
- Extended tests to cover:
  - Rate limiting behavior and error messages.
  - `/status` handler output including printer online and paper status.
- Ensured `MOCK_PRINTER=true` continues to work with the new APIs and configuration, so you can run and test the bot without a physical printer attached.

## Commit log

2026-02-10 Update requirements.txt to reflect Python version compatibility and change thermal printer library
2026-02-10 Add async printer module with MockPrinter for testing, including pytest configuration and initial tests for AsyncPrinter functionality.
2026-02-10 Add comprehensive pytest suite for bot.py, including tests for authentication and throttling middleware, command handlers, and message handling. Also, update print logging assertions in AsyncPrinter 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
2026-02-10 Add README.md with detailed project documentation, including installation instructions, functionality overview, usage guidelines, and logging configuration for the Telegram Printer Bot.
2026-02-10 Add systemd service support for Telegram Printer Bot, including generation of bot.service file and installation instructions in setup.py and README.md.
2026-02-10 Update README.md with additional system library installation instructions for Raspberry Pi and Debian; add pyserial to requirements.txt for serial communication support.
2026-02-10 Update throttling middleware to use configurable print rate limit and enhance user feedback in error messages. Add new configuration options for serial settings and update README.md to reflect change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
2026-02-10 Add new text styling options and codepage configuration for printer in config.py. Update AsyncPrinter to utilize these settings for improved text formatting and encoding. Enhance README.md with new c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
2026-02-10 Add codepage_tables.py to print ESC/POS code page tables on thermal printers. Implement functionality to select and display code pages by name or numeric ID, utilizing configuration settings for seri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
2026-02-10 Refactor print_codepage function in codepage_tables.py to ensure ASCII encoding for all output. Update header, body, and footer printing to handle byte encoding and replace errors, improving compatib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
2026-02-10 Update print_codepage and main functions in codepage_tables.py to adjust font size and alignment settings for improved output formatting on thermal printers.
2026-02-10 Update AsyncPrinter to include codepage configuration for text encoding. Change encoding method to use ASCII for improved compatibility with printers.
2026-02-10 Update CODEPAGE configuration in config.py to use integer values and modify AsyncPrinter to directly print text without encoding, improving compatibility with printers.
2026-02-10 Refactor AsyncPrinter to improve text printing functionality by integrating updated CODEPAGE configuration and enhancing error handling for better compatibility with various printer models.
2026-02-10 Refactor test_encoding.py to simplify encoding tests by removing command-line arguments and directly using a default text. Update text encoding to cp1251 for improved compatibility with printers.
2026-02-10 Fix encoding in test_encoding.py by removing unnecessary decode step and directly encoding the text to cp1251, ensuring compatibility with printers.
2026-02-10 Refactor test_encoding.py to streamline encoding tests by removing command-line argument handling. Directly send the default text "Привет, мир!" encoded in cp1251 to the printer, enhancing compatibil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
2026-02-10 Refactor test_encoding.py to utilize python-escpos for printing Cyrillic text. Simplify the code by removing direct serial communication and enhancing text encoding handling for improved compatibilit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
2026-02-10 Add profile parameter to printer initialization and simplify text printing in test_encoding.py
2026-02-10 Enhance printer configuration by adding CODEPAGE_ID and PRINTER_PROFILE parameters. Update AsyncPrinter to utilize these settings for improved text encoding and compatibility with various printer mod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
2026-02-10 Update ThrottlingMiddleware to allow configurable rate limits. Modify help text to reflect dynamic print rate and enhance user feedback for rate limit exceeded responses.
2026-02-10 Enhance ThrottlingMiddleware to bypass rate limiting for command messages and service updates. Add new test scripts for printing code page tables and testing Cyrillic output, improving printer compat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
2026-02-10 Enhance printer status reporting in bot.py to include paper status details. Update AsyncPrinter to return both online and paper status, and add corresponding tests in test_bot.py to verify the change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
2026-02-10 Add CHANGELOG.md for version 0.1.0 detailing printer configuration, Cyrillic support, and bot UX improvements. Update .gitignore to exclude release files.
2026-02-10 Adjust text wrapping in handle_message to dynamically set width based on selected font, improving print formatting for different font types.
2026-02-10 Add QR code printing functionality to AsyncPrinter and bot. Introduce textln method in MockPrinter for line-oriented text. Update help text to include QR command and enforce QR text length limit.
2026-02-11 Update text wrapping width in handle_message to improve print formatting for Font A, adjusting from 42 to 32 columns.
2026-02-11 Refactor text wrapping logic in handle_message for clarity and maintainability. Update default TEXT_WIDTH and TEXT_HEIGHT in config.py to improve print quality and reduce PRINT_RATE_LIMIT_SECONDS for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
2026-02-11 Update text wrapping logic in handle_message to a fixed width of 52 columns for improved print formatting consistency.
2026-02-11 Refactor paper status reporting in status_handler for clarity and update text wrapping logic in handle_message to dynamically adjust based on font selection, enhancing print formatting consistency.
2026-02-11 Add QR code configuration options in config.py and update print_qr method in AsyncPrinter to utilize these settings for improved QR code printing functionality.
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2026-02-11 qr printing fix
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2026-02-16 Update CHANGELOG and README for v0.1.3: Add text formatting features and correct font character limits. Enhance Telegram formatting options for printed text.
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2026-02-16 Refactor printer state management after image and QR printing
    - Introduced _reinitialize_printer method to send ESC/POS initialize sequence, ensuring the printer resets to a default state after image or QR code printing.
    - Updated AsyncPrinter to call _reinitialize_printer instead of _reset_style for better clarity and functionality.
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2026-02-21 assembly instruction and printer case 3d printing
    [Printer Case.3mf, Printer Case.step, schematic.fzz]
2026-02-21 Enhance assembly instructions for JotPrintBot, including detailed BOM, wiring steps, and 3D printing guidelines. Add safety notes and improve formatting for clarity.
    [schematic.fzz]
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

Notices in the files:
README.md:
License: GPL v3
